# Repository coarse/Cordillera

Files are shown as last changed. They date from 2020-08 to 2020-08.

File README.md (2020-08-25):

# Cordillera



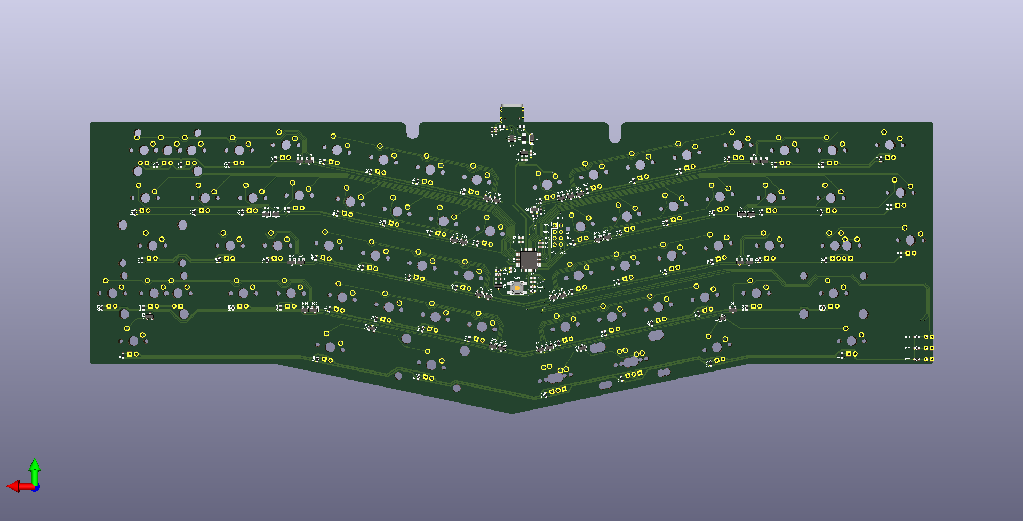
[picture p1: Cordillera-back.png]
Back PCB Render

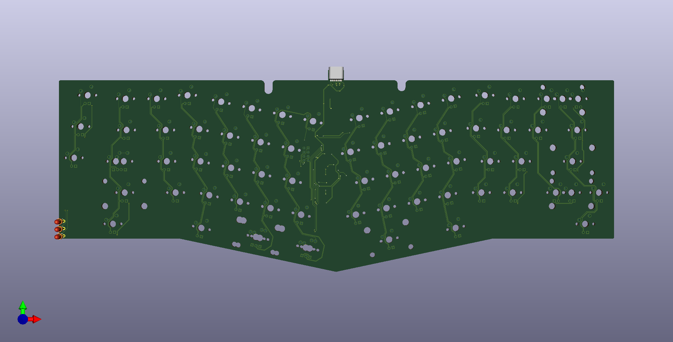
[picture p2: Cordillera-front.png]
Front PCB Render


## About

The Cordillera PCB is an open design PCB heavily based on the Alice PCB. The only breaking change is the USB connector which renders it unusable on most Alice cases.

- STM32F072 controller
- USB C connector mounted at the top
- ESD, over voltage, and over current protection circuits
- Dual common cathode diodes instead of single ones
- Backlight, single color
- Fancy "press to reset, hold for bootloader" reset circuit

## Dependencies

Symbols and footprints used are from my [KiCad library](https://github.com/coarse/KiCad-Keeb-Lib)

## Notes

- Original Alice uses USB Mini, so this PCB may be incompatible with some Alice cases

## Disclaimer

I provide this design as a reference for designing similar keyboard layout PCBs. Using them within your projects will require a will to do research of one's own and to learn the workings of them, potentially fixing issues if they exist.

I present the design as-is and as-available, without liability and without any guarantees regarding functionality, as expressed in the license.

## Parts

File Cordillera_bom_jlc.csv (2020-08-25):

Comment | Designator | Footprint | LCSC Part # | Manufacturer | Manufacturer Part Number
10n | C1 | keeb_parts:C_0603_1608Metric | C1589 | Samsung Electro-Mechanics | CL10B103KB8NNNC
100n | C2,C3,C5 | keeb_parts:C_0603_1608Metric | C1591 | Samsung Electro-Mechanics | CL10B104KB8NNNC
4.7n | C7 | keeb_parts:C_0603_1608Metric | C1621 | Samsung Electro-Mechanics | CL10B472KB8NNNC
4.7u | C6,C8,C11 | keeb_parts:C_0603_1608Metric | C1705 | Samsung Electro-Mechanics | CL10A475KP8NNNC
1u | C4,C9,C10,C12 | keeb_parts:C_0603_1608Metric | C1592 | Samsung Electro-Mechanics | CL10A105KO8NNNC
SMF6.0CA | D1 | keeb_parts:D_SOD-123 | C123791 | MDD(Microdiode Electronics) | SMF6.0CA
BAV70 | D2,D3,D4,D5,D6,D7,D8,D9,D10,D11,D12,D13,D14,D15,D16,D17,D18,D19,D20,D21,D22,D23,D24,D25,D26,D27,D28,D29,D30,D31,D32,D33,D34,D35,D36,D37 | keeb_parts:SOT-23 | C2501 | Nexperia | BAV70,215
1A | F1 | keeb_parts:Fuse_1206_3216Metric | C151162 | Littelfuse | 1206L050/15YR
2N7002 | Q1,Q2 | keeb_parts:SOT-23 | C65189 | Nexperia | 2N7002,215
1M | R1 | keeb_parts:R_0603_1608Metric | C26098 | UNI-ROYAL(Uniroyal Elec) | 0603WAJ0105T5E
5.1k | R2,R3 | keeb_parts:R_0603_1608Metric | C26000 | UNI-ROYAL(Uniroyal Elec) | 0603WAJ0512T5E
10k | R4,R6,R8 | keeb_parts:R_0603_1608Metric | C15401 | UNI-ROYAL(Uniroyal Elec) | 0603WAJ0103T5E
470 | R5,R9,R10,R11,R12,R13,R14,R15,R16,R17,R18,R19,R20,R21,R22,R23,R24,R25,R26,R27,R28,R29,R30,R31,R32,R33,R34,R35,R36,R37,R38,R39,R40,R41,R42,R43,R44,R45,R46,R47,R48,R49,R50,R51,R52,R53,R54,R55,R56,R57,R58,R59,R60,R61,R62,R63,R64,R65,R66,R67,R68,R69,R70,R71,R72,R73,R74,R75,R76,R77 | keeb_parts:R_0603_1608Metric | C1211 | UNI-ROYAL(Uniroyal Elec) | 0603WAJ0470T5E
100k | R7 | keeb_parts:R_0603_1608Metric | C15458 | UNI-ROYAL(Uniroyal Elec) | 0603WAJ0104T5E
SW_SPST | SW1 | keeb_parts:TactSwitch_SPST_5.1x5.1mm | C318884 | XKB Connectivity | TS-1187A-B-A-B
STM32F072CBTx | U1 | keeb_mcu:LQFP-48_7x7mm_P0.5mm | C81720 | STMicroelectronics | STM32F072CBT6
XC6206P332MR | U2 | keeb_parts:SOT-23 | C5446 | Torex Semicon | XC6206P332MR
SRV05-4 | U3 | keeb_parts:SOT-23-6 | C85364 | ProTek Devices | SRV05-4-P-T7
HRO-TYPE-C-31-M-12 | USB1 | keeb_connectors:HRO-TYPE-C-31-M-12 | C165948 | Korean Hroparts Elec | TYPE-C-31-M-12

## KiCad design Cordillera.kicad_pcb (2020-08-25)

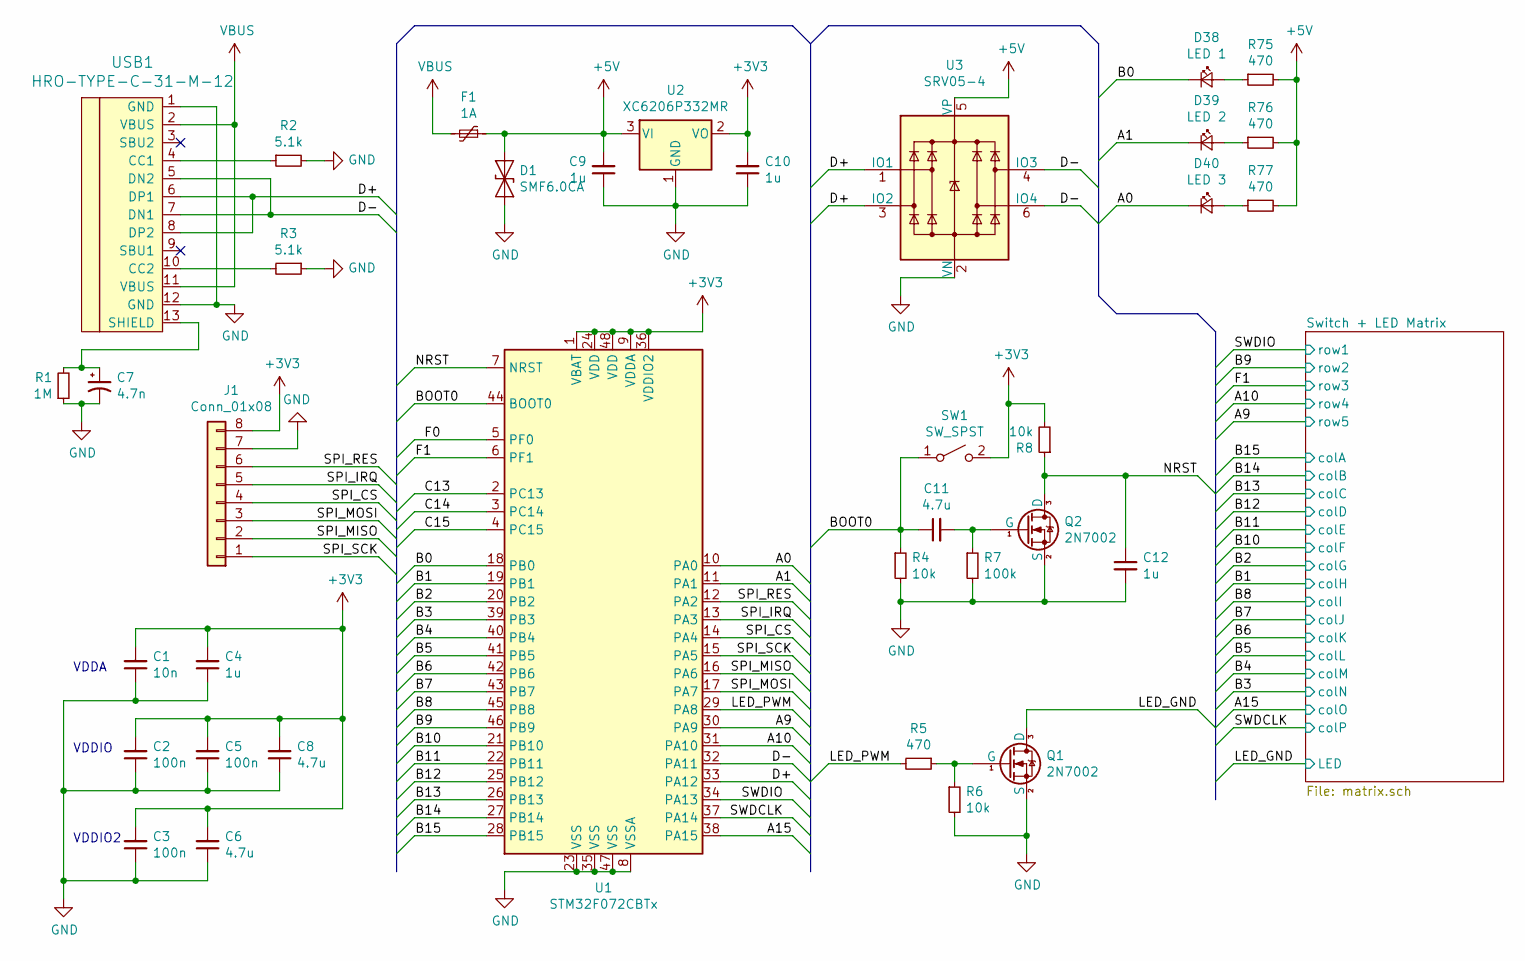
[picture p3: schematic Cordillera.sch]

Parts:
C1: 10n; C_0603_1608Metric
C2, C3, C5: 100n; C_0603_1608Metric
C4, C9, C10, C12: 1u; C_0603_1608Metric
C6, C8, C11: 4.7u; C_0603_1608Metric
C7: 4.7n; C_0603_1608Metric
D1: SMF6.0CA; D_SOD-123
D38: LED 1; LED_D3.0mm
D39: LED 2; LED_D3.0mm
D40: LED 3; LED_D3.0mm
F1: 1A; Fuse_1206_3216Metric
J1: Conn_01x08; PinHeader_2x04_P2.54mm_Vertical
Q1, Q2: 2N7002; SOT-23
R1: 1M; R_0603_1608Metric
R2, R3: 5.1k; R_0603_1608Metric
R4, R6, R8: 10k; R_0603_1608Metric
R5, R75, R76, R77: 470; R_0603_1608Metric
R7: 100k; R_0603_1608Metric
SW1: SW_SPST; TactSwitch_SPST_5.1x5.1mm
U1: STM32F072CBTx; LQFP-48_7x7mm_P0.5mm
U2: XC6206P332MR; SOT-23
U3: SRV05-4; SOT-23-6
USB1: HRO-TYPE-C-31-M-12

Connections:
+3V3: C1.2, C2.2, C3.2, C4.2, C5.2, C6.2, C8.2, C10.2, J1.8, R8.2, SW1.2 (B), U1.1 (VBAT), U1.9 (VDDA), U1.24 (VDD), U1.36 (VDDIO2), U1.48 (VDD), U2.2 (VO)
+5V: C9.2, D1.1 (A1), F1.1, R75.2, R76.2, R77.2, U2.3 (VI), U3.5 (VP); also elsewhere on the board
/A0: D40.1 (K), U1.10 (PA0)
/A1: D39.1 (K), U1.11 (PA1)
/A9: U1.30 (PA9); also elsewhere on the board
/A10: U1.31 (PA10); also elsewhere on the board
/A15: U1.38 (PA15); also elsewhere on the board
/B0: D38.1 (K), U1.18 (PB0)
/B1: U1.19 (PB1); also elsewhere on the board
/B2: U1.20 (PB2); also elsewhere on the board
/B3: U1.39 (PB3); also elsewhere on the board
/B4: U1.40 (PB4); also elsewhere on the board
/B5: U1.41 (PB5); also elsewhere on the board
/B6: U1.42 (PB6); also elsewhere on the board
/B7: U1.43 (PB7); also elsewhere on the board
/B8: U1.45 (PB8); also elsewhere on the board
/B9: U1.46 (PB9); also elsewhere on the board
/B10: U1.21 (PB10); also elsewhere on the board
/B11: U1.22 (PB11); also elsewhere on the board
/B12: U1.25 (PB12); also elsewhere on the board
/B13: U1.26 (PB13); also elsewhere on the board
/B14: U1.27 (PB14); also elsewhere on the board
/B15: U1.28 (PB15); also elsewhere on the board
/BOOT0: C11.1, R4.1, SW1.1 (A), U1.44 (BOOT0)
/C13: U1.2 (PC13)
/C14: U1.3 (PC14)
/C15: U1.4 (PC15)
/D+: U1.33 (PA12), U3.1 (IO1), U3.3 (IO2), USB1.6 (DP1), USB1.8 (DP2)
/D-: U1.32 (PA11), U3.4 (IO3), U3.6 (IO4), USB1.5 (DN2), USB1.7 (DN1)
/F0: U1.5 (PF0)
/F1: U1.6 (PF1); also elsewhere on the board
/LED_GND: Q1.3 (D); also elsewhere on the board
/LED_PWM: R5.2, U1.29 (PA8)
/NRST: C12.1, Q2.3 (D), R8.1, U1.7 (NRST)
/SPI_CS: J1.4, U1.14 (PA4)
/SPI_IRQ: J1.5, U1.13 (PA3)
/SPI_MISO: J1.2, U1.16 (PA6)
/SPI_MOSI: J1.3, U1.17 (PA7)
/SPI_RES: J1.6, U1.12 (PA2)
/SPI_SCK: J1.1, U1.15 (PA5)
/SWDCLK: U1.37 (PA14); also elsewhere on the board
/SWDIO: U1.34 (PA13); also elsewhere on the board
GND: C1.1, C2.1, C3.1, C4.1, C5.1, C6.1, C7.2, C8.1, C9.1, C10.1, C12.2, D1.2 (A2), J1.7, Q1.2 (S), Q2.2 (S), R1.1, R2.2, R3.1, R4.2, R6.2, R7.2, U1.8 (VSSA), U1.23 (VSS), U1.35 (VSS), U1.47 (VSS), U2.1 (GND), U3.2 (VN), USB1.1 (GND), USB1.12 (GND)
unnamed: C7.1, R1.2, USB1.13 (SHIELD)
unnamed: C11.2, Q2.1 (G), R7.1
unnamed: D38.2 (A), R75.1
unnamed: D39.2 (A), R76.1
unnamed: D40.2 (A), R77.1
unnamed: Q1.1 (G), R5.1, R6.1
unnamed: R2.1, USB1.4 (CC1)
unnamed: R3.2, USB1.10 (CC2)
VBUS: F1.2, USB1.2 (VBUS), USB1.11 (VBUS)

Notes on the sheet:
VDDIO
VDDIO2
VDDA

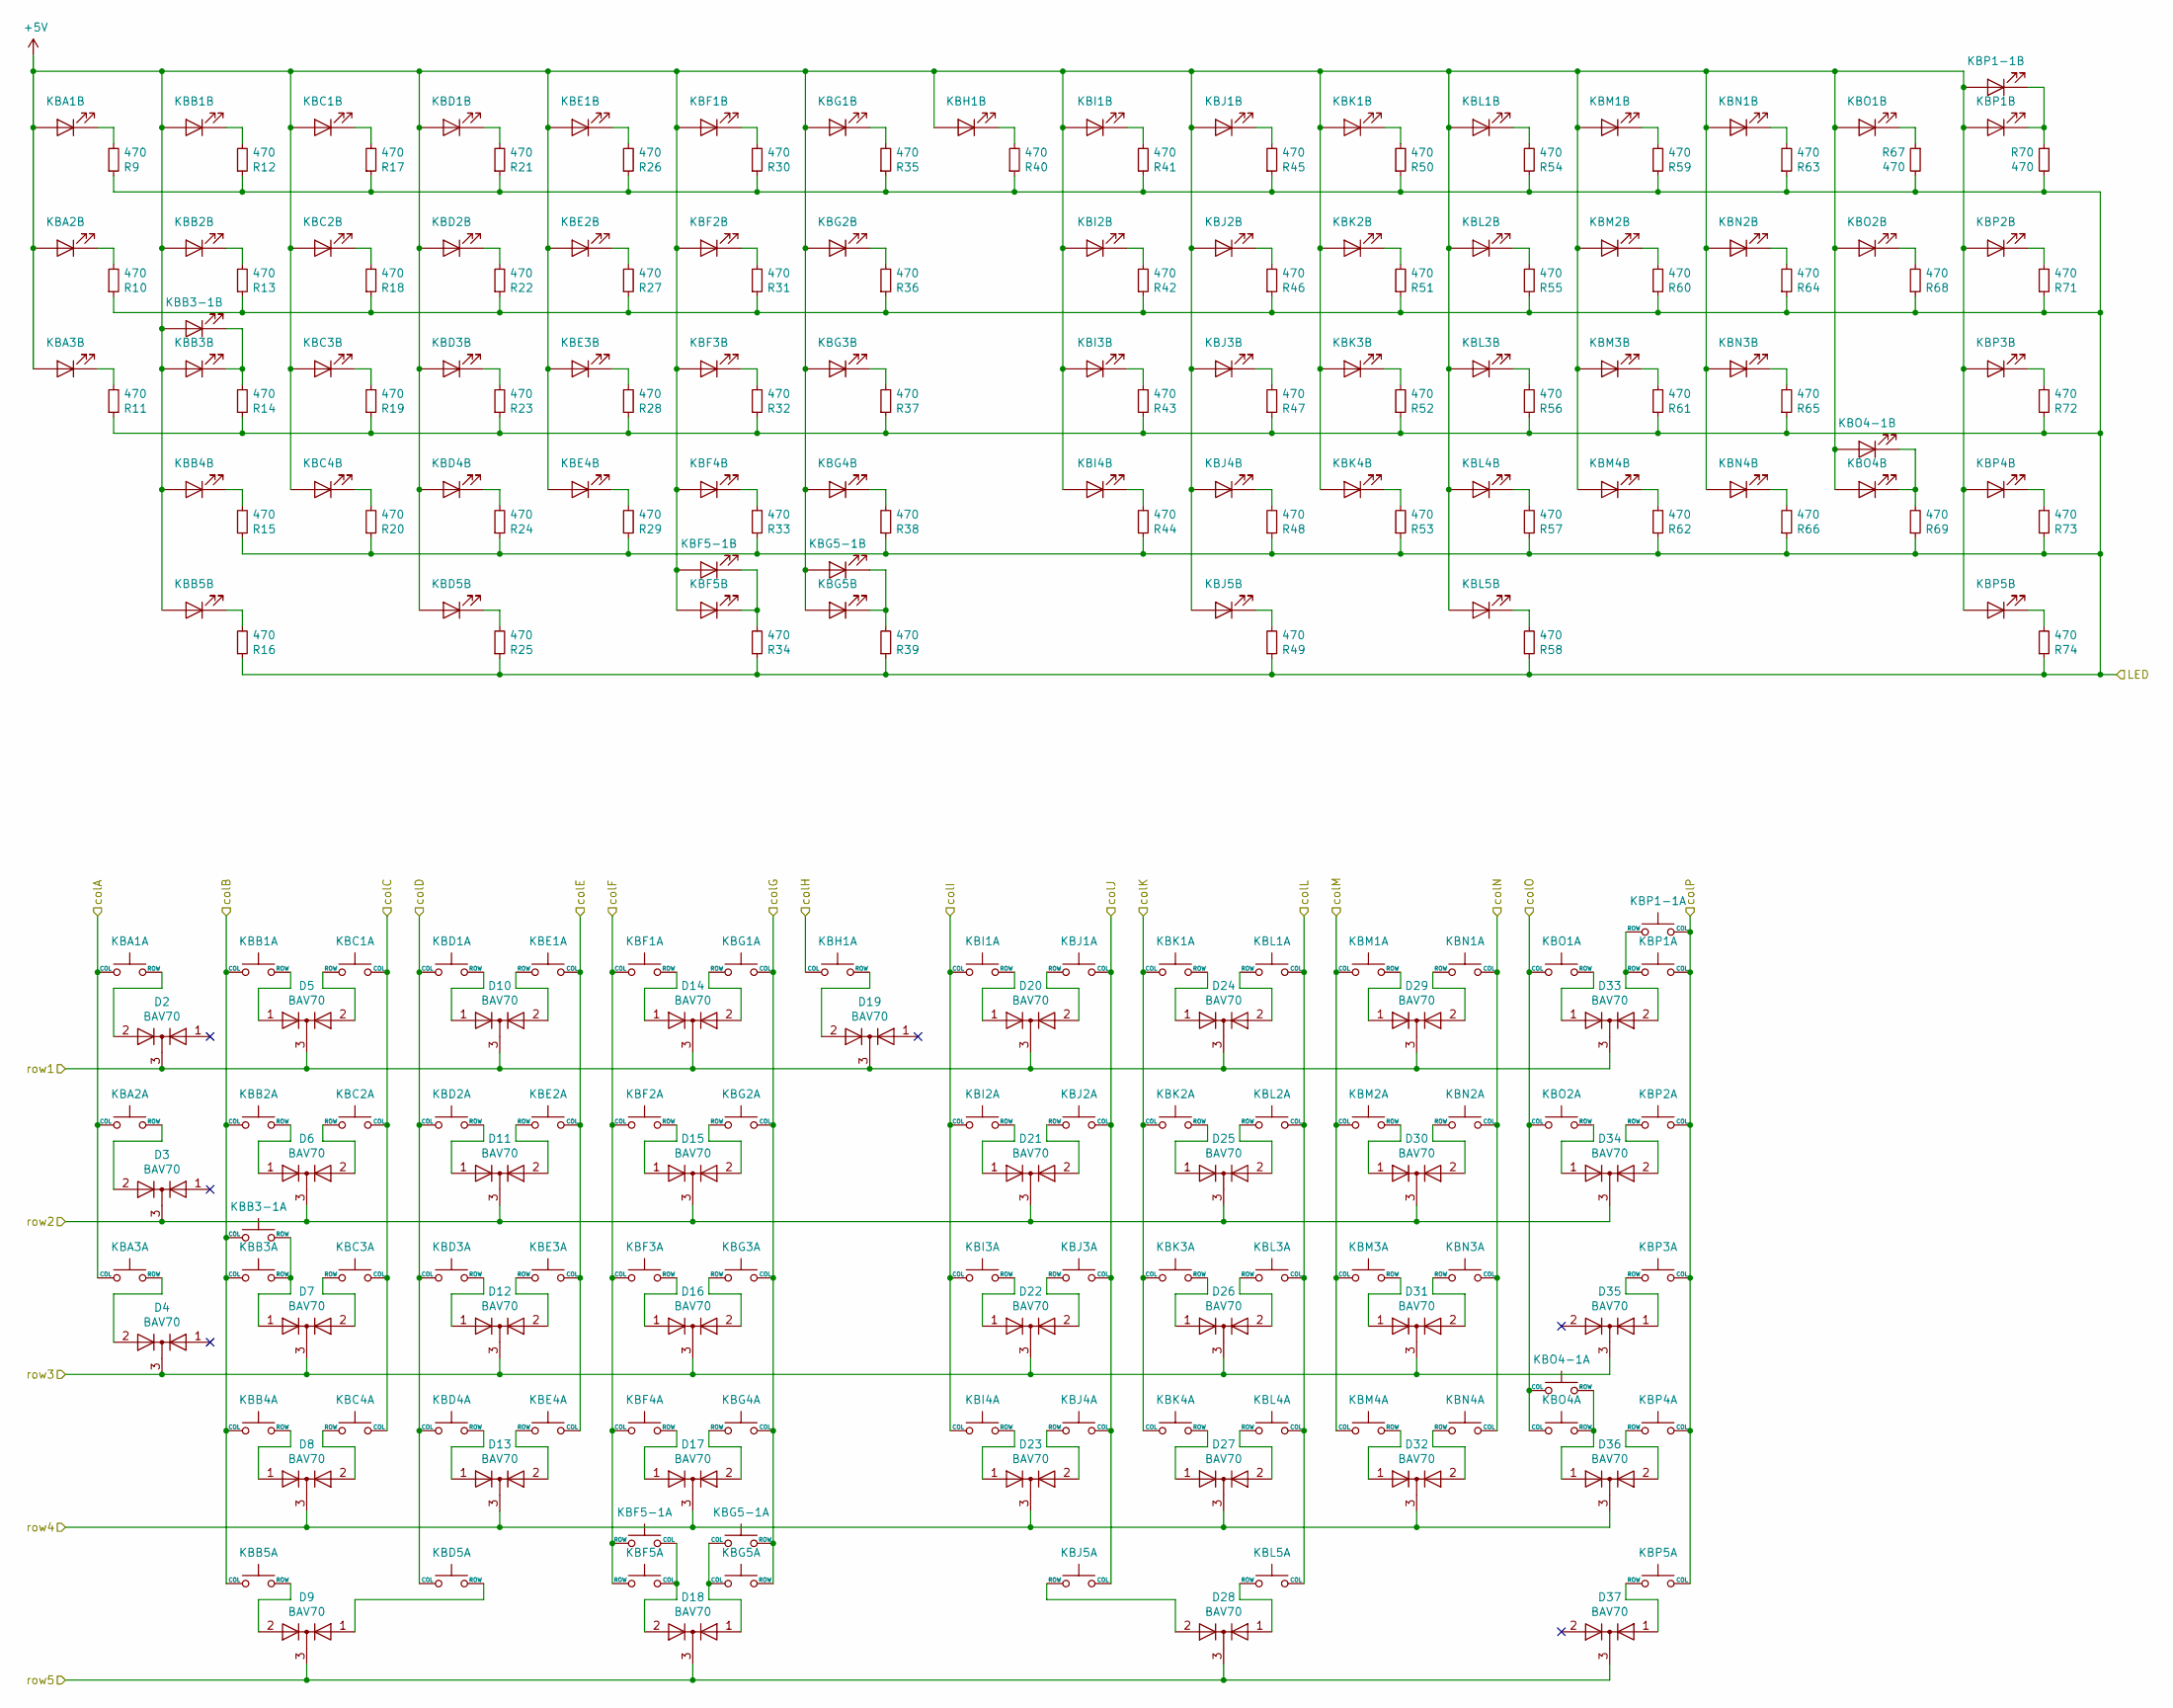
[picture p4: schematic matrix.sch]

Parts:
D2, D3, D4, D5, D6, D7, D8, D9, D10, D11, D12, D13, D14, D15, D16, D17, D18, D19, D20, D21, D22, D23, D24, D25, D26, D27, D28, D29, D30, D31, D32, D33, D34, D35, D36, D37: BAV70; SOT-23
KBA1, KBA2, KBA3: Keyboard_Switch; MXOnly-1U
KBB1: Keyboard_Switch; MXOnly-1U
KBB2, KBB5: Keyboard_Switch; MXOnly-1.5U
KBB3: Keyboard_Switch; MXOnly-1.75U
KBB3-1: Keyboard_Switch; MXOnly-1.25U-FLIPPED
KBB4: Keyboard_Switch; MXOnly-2.25U
KBC1, KBC2, KBC3, KBC4: Keyboard_Switch; MXOnly-1U
KBD1, KBD2, KBD3, KBD4: Keyboard_Switch; MXOnly-1U
KBD5: Keyboard_Switch; MXOnly-1.5U
KBE1, KBE2, KBE3, KBE4: Keyboard_Switch; MXOnly-1U
KBF1, KBF2, KBF3, KBF4: Keyboard_Switch; MXOnly-1U
KBF5: Keyboard_Switch; MXOnly-2U-FLIPPED-ReversedStabilizers
KBF5-1: Keyboard_Switch; MXOnly-2.25U-ReversedStabilizers
KBG1, KBG2, KBG3, KBG4, KBG5-1: Keyboard_Switch; MXOnly-1U
KBG5: Keyboard_Switch; MXOnly-1.25U-FLIPPED
KBH1: Keyboard_Switch; MXOnly-1U
KBI1, KBI2, KBI3, KBI4: Keyboard_Switch; MXOnly-1U
KBJ1, KBJ2, KBJ3, KBJ4: Keyboard_Switch; MXOnly-1U
KBJ5: Keyboard_Switch; MXOnly-2.75U-ReversedStabilizers
KBK1, KBK2, KBK3, KBK4: Keyboard_Switch; MXOnly-1U
KBL1, KBL2, KBL3, KBL4: Keyboard_Switch; MXOnly-1U
KBL5: Keyboard_Switch; MXOnly-1.5U
KBM1, KBM2, KBM3, KBM4: Keyboard_Switch; MXOnly-1U
KBN1, KBN2, KBN3, KBN4: Keyboard_Switch; MXOnly-1U
KBO1, KBO2: Keyboard_Switch; MXOnly-1U
KBO4: Keyboard_Switch; MXOnly-2.75U
KBO4-1: Keyboard_Switch; MXOnly-1.75U-FLIPPED
KBP1: Keyboard_Switch; MXOnly-2U
KBP1-1: Keyboard_Switch; MXOnly-1U-FLIPPED
KBP2, KBP5: Keyboard_Switch; MXOnly-1.5U
KBP3: Keyboard_Switch; MXOnly-2.25U-ReversedStabilizers
KBP4: Keyboard_Switch; MXOnly-1U
R9, R10, R11, R12, R13, R14, R15, R16, R17, R18, R19, R20, R21, R22, R23, R24, R25, R26, R27, R28, R29, R30, R31, R32, R33, R34, R35, R36, R37, R38, R39, R40, R41, R42, R43, R44, R45, R46, R47, R48, R49, R50, R51, R52, R53, R54, R55, R56, R57, R58, R59, R60, R61, R62, R63, R64, R65, R66, R67, R68, R69, R70, R71, R72, R73, R74: 470; R_0603_1608Metric

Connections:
+5V: KBA1.3 (LED), KBA2.3 (LED), KBA3.3 (LED), KBB1.3 (LED), KBB2.3 (LED), KBB3.3 (LED), KBB3-1.3 (LED), KBB4.3 (LED), KBB5.3 (LED), KBC1.3 (LED), KBC2.3 (LED), KBC3.3 (LED), KBC4.3 (LED), KBD1.3 (LED), KBD2.3 (LED), KBD3.3 (LED), KBD4.3 (LED), KBD5.3 (LED), KBE1.3 (LED), KBE2.3 (LED), KBE3.3 (LED), KBE4.3 (LED), KBF1.3 (LED), KBF2.3 (LED), KBF3.3 (LED), KBF4.3 (LED), KBF5.3 (LED), KBF5-1.3 (LED), KBG1.3 (LED), KBG2.3 (LED), KBG3.3 (LED), KBG4.3 (LED), KBG5.3 (LED), KBG5-1.3 (LED), KBH1.3 (LED), KBI1.3 (LED), KBI2.3 (LED), KBI3.3 (LED), KBI4.3 (LED), KBJ1.3 (LED), KBJ2.3 (LED), KBJ3.3 (LED), KBJ4.3 (LED), KBJ5.3 (LED), KBK1.3 (LED), KBK2.3 (LED), KBK3.3 (LED), KBK4.3 (LED), KBL1.3 (LED), KBL2.3 (LED), KBL3.3 (LED), KBL4.3 (LED), KBL5.3 (LED), KBM1.3 (LED), KBM2.3 (LED), KBM3.3 (LED), KBM4.3 (LED), KBN1.3 (LED), KBN2.3 (LED), KBN3.3 (LED), KBN4.3 (LED), KBO1.3 (LED), KBO2.3 (LED), KBO4.3 (LED), KBO4-1.3 (LED), KBP1.3 (LED), KBP1-1.3 (LED), KBP2.3 (LED), KBP3.3 (LED), KBP4.3 (LED), KBP5.3 (LED); also elsewhere on the board
/A9: D9.3 (K), D18.3 (K), D28.3 (K), D37.3 (K); also elsewhere on the board
/A10: D8.3 (K), D13.3 (K), D17.3 (K), D23.3 (K), D27.3 (K), D32.3 (K), D36.3 (K); also elsewhere on the board
/A15: KBO1.1 (COL), KBO2.1 (COL), KBO4.1 (COL), KBO4-1.1 (COL); also elsewhere on the board
/B1: KBH1.1 (COL); also elsewhere on the board
/B2: KBG1.1 (COL), KBG2.1 (COL), KBG3.1 (COL), KBG4.1 (COL), KBG5.2 (ROW), KBG5-1.2 (ROW); also elsewhere on the board
/B3: KBN1.1 (COL), KBN2.1 (COL), KBN3.1 (COL), KBN4.1 (COL); also elsewhere on the board
/B4: KBM1.1 (COL), KBM2.1 (COL), KBM3.1 (COL), KBM4.1 (COL); also elsewhere on the board
/B5: KBL1.1 (COL), KBL2.1 (COL), KBL3.1 (COL), KBL4.1 (COL), KBL5.1 (COL); also elsewhere on the board
/B6: KBK1.1 (COL), KBK2.1 (COL), KBK3.1 (COL), KBK4.1 (COL); also elsewhere on the board
/B7: KBJ1.1 (COL), KBJ2.1 (COL), KBJ3.1 (COL), KBJ4.1 (COL), KBJ5.1 (COL); also elsewhere on the board
/B8: KBI1.1 (COL), KBI2.1 (COL), KBI3.1 (COL), KBI4.1 (COL); also elsewhere on the board
/B9: D3.3 (K), D6.3 (K), D11.3 (K), D15.3 (K), D21.3 (K), D25.3 (K), D30.3 (K), D34.3 (K); also elsewhere on the board
/B10: KBF1.1 (COL), KBF2.1 (COL), KBF3.1 (COL), KBF4.1 (COL), KBF5.2 (ROW), KBF5-1.2 (ROW); also elsewhere on the board
/B11: KBE1.1 (COL), KBE2.1 (COL), KBE3.1 (COL), KBE4.1 (COL); also elsewhere on the board
/B12: KBD1.1 (COL), KBD2.1 (COL), KBD3.1 (COL), KBD4.1 (COL), KBD5.1 (COL); also elsewhere on the board
/B13: KBC1.1 (COL), KBC2.1 (COL), KBC3.1 (COL), KBC4.1 (COL); also elsewhere on the board
/B14: KBB1.1 (COL), KBB2.1 (COL), KBB3.1 (COL), KBB3-1.1 (COL), KBB4.1 (COL), KBB5.1 (COL); also elsewhere on the board
/B15: KBA1.1 (COL), KBA2.1 (COL), KBA3.1 (COL); also elsewhere on the board
/F1: D4.3 (K), D7.3 (K), D12.3 (K), D16.3 (K), D22.3 (K), D26.3 (K), D31.3 (K), D35.3 (K); also elsewhere on the board
/LED_GND: R9.1, R10.1, R11.1, R12.1, R13.1, R14.1, R15.1, R16.1, R17.1, R18.1, R19.1, R20.1, R21.1, R22.1, R23.1, R24.1, R25.1, R26.1, R27.1, R28.1, R29.1, R30.1, R31.1, R32.1, R33.1, R34.1, R35.1, R36.1, R37.1, R38.1, R39.1, R40.1, R41.1, R42.1, R43.1, R44.1, R45.1, R46.1, R47.1, R48.1, R49.1, R50.1, R51.1, R52.1, R53.1, R54.1, R55.1, R56.1, R57.1, R58.1, R59.1, R60.1, R61.1, R62.1, R63.1, R64.1, R65.1, R66.1, R67.2, R68.1, R69.1, R70.2, R71.1, R72.1, R73.1, R74.1; also elsewhere on the board
/SWDCLK: KBP1.1 (COL), KBP1-1.1 (COL), KBP2.1 (COL), KBP3.1 (COL), KBP4.1 (COL), KBP5.1 (COL); also elsewhere on the board
/SWDIO: D2.3 (K), D5.3 (K), D10.3 (K), D14.3 (K), D19.3 (K), D20.3 (K), D24.3 (K), D29.3 (K), D33.3 (K); also elsewhere on the board
unnamed: D2.2 (A), KBA1.2 (ROW)
unnamed: D3.2 (A), KBA2.2 (ROW)
unnamed: D4.2 (A), KBA3.2 (ROW)
unnamed: D5.1 (A), KBB1.2 (ROW)
unnamed: D5.2 (A), KBC1.2 (ROW)
unnamed: D6.1 (A), KBB2.2 (ROW)
unnamed: D6.2 (A), KBC2.2 (ROW)
unnamed: D7.1 (A), KBB3.2 (ROW), KBB3-1.2 (ROW)
unnamed: D7.2 (A), KBC3.2 (ROW)
unnamed: D8.1 (A), KBB4.2 (ROW)
unnamed: D8.2 (A), KBC4.2 (ROW)
unnamed: D9.1 (A), KBD5.2 (ROW)
unnamed: D9.2 (A), KBB5.2 (ROW)
unnamed: D10.1 (A), KBD1.2 (ROW)
unnamed: D10.2 (A), KBE1.2 (ROW)
unnamed: D11.1 (A), KBD2.2 (ROW)
unnamed: D11.2 (A), KBE2.2 (ROW)
unnamed: D12.1 (A), KBD3.2 (ROW)
unnamed: D12.2 (A), KBE3.2 (ROW)
unnamed: D13.1 (A), KBD4.2 (ROW)
unnamed: D13.2 (A), KBE4.2 (ROW)
unnamed: D14.1 (A), KBF1.2 (ROW)
unnamed: D14.2 (A), KBG1.2 (ROW)
unnamed: D15.1 (A), KBF2.2 (ROW)
unnamed: D15.2 (A), KBG2.2 (ROW)
unnamed: D16.1 (A), KBF3.2 (ROW)
unnamed: D16.2 (A), KBG3.2 (ROW)
unnamed: D17.1 (A), KBF4.2 (ROW)
unnamed: D17.2 (A), KBG4.2 (ROW)
unnamed: D18.1 (A), KBG5.1 (COL), KBG5-1.1 (COL)
unnamed: D18.2 (A), KBF5.1 (COL), KBF5-1.1 (COL)
unnamed: D19.2 (A), KBH1.2 (ROW)
unnamed: D20.1 (A), KBI1.2 (ROW)
unnamed: D20.2 (A), KBJ1.2 (ROW)
unnamed: D21.1 (A), KBI2.2 (ROW)
unnamed: D21.2 (A), KBJ2.2 (ROW)
unnamed: D22.1 (A), KBI3.2 (ROW)
unnamed: D22.2 (A), KBJ3.2 (ROW)
unnamed: D23.1 (A), KBI4.2 (ROW)
unnamed: D23.2 (A), KBJ4.2 (ROW)
unnamed: D24.1 (A), KBK1.2 (ROW)
unnamed: D24.2 (A), KBL1.2 (ROW)
unnamed: D25.1 (A), KBK2.2 (ROW)
unnamed: D25.2 (A), KBL2.2 (ROW)
unnamed: D26.1 (A), KBK3.2 (ROW)
unnamed: D26.2 (A), KBL3.2 (ROW)
unnamed: D27.1 (A), KBK4.2 (ROW)
unnamed: D27.2 (A), KBL4.2 (ROW)
unnamed: D28.1 (A), KBL5.2 (ROW)
unnamed: D28.2 (A), KBJ5.2 (ROW)
unnamed: D29.1 (A), KBM1.2 (ROW)
unnamed: D29.2 (A), KBN1.2 (ROW)
unnamed: D30.1 (A), KBM2.2 (ROW)
unnamed: D30.2 (A), KBN2.2 (ROW)
unnamed: D31.1 (A), KBM3.2 (ROW)
unnamed: D31.2 (A), KBN3.2 (ROW)
unnamed: D32.1 (A), KBM4.2 (ROW)
unnamed: D32.2 (A), KBN4.2 (ROW)
unnamed: D33.1 (A), KBO1.2 (ROW)
unnamed: D33.2 (A), KBP1.2 (ROW), KBP1-1.2 (ROW)
unnamed: D34.1 (A), KBO2.2 (ROW)
unnamed: D34.2 (A), KBP2.2 (ROW)
unnamed: D35.1 (A), KBP3.2 (ROW)
unnamed: D36.1 (A), KBO4.2 (ROW), KBO4-1.2 (ROW)
unnamed: D36.2 (A), KBP4.2 (ROW)
unnamed: D37.1 (A), KBP5.2 (ROW)
unnamed: KBA1.4 (LEDGND), R9.2
unnamed: KBA2.4 (LEDGND), R10.2
unnamed: KBA3.4 (LEDGND), R11.2
unnamed: KBB1.4 (LEDGND), R12.2
unnamed: KBB2.4 (LEDGND), R13.2
unnamed: KBB3.4 (LEDGND), KBB3-1.4 (LEDGND), R14.2
unnamed: KBB4.4 (LEDGND), R15.2
unnamed: KBB5.4 (LEDGND), R16.2
unnamed: KBC1.4 (LEDGND), R17.2
unnamed: KBC2.4 (LEDGND), R18.2
unnamed: KBC3.4 (LEDGND), R19.2
unnamed: KBC4.4 (LEDGND), R20.2
unnamed: KBD1.4 (LEDGND), R21.2
unnamed: KBD2.4 (LEDGND), R22.2
unnamed: KBD3.4 (LEDGND), R23.2
unnamed: KBD4.4 (LEDGND), R24.2
unnamed: KBD5.4 (LEDGND), R25.2
unnamed: KBE1.4 (LEDGND), R26.2
unnamed: KBE2.4 (LEDGND), R27.2
unnamed: KBE3.4 (LEDGND), R28.2
unnamed: KBE4.4 (LEDGND), R29.2
unnamed: KBF1.4 (LEDGND), R30.2
unnamed: KBF2.4 (LEDGND), R31.2
unnamed: KBF3.4 (LEDGND), R32.2
unnamed: KBF4.4 (LEDGND), R33.2
unnamed: KBF5.4 (LEDGND), KBF5-1.4 (LEDGND), R34.2
unnamed: KBG1.4 (LEDGND), R35.2
unnamed: KBG2.4 (LEDGND), R36.2
unnamed: KBG3.4 (LEDGND), R37.2
unnamed: KBG4.4 (LEDGND), R38.2
unnamed: KBG5.4 (LEDGND), KBG5-1.4 (LEDGND), R39.2
unnamed: KBH1.4 (LEDGND), R40.2
unnamed: KBI1.4 (LEDGND), R41.2
unnamed: KBI2.4 (LEDGND), R42.2
unnamed: KBI3.4 (LEDGND), R43.2
unnamed: KBI4.4 (LEDGND), R44.2
unnamed: KBJ1.4 (LEDGND), R45.2
unnamed: KBJ2.4 (LEDGND), R46.2
unnamed: KBJ3.4 (LEDGND), R47.2
unnamed: KBJ4.4 (LEDGND), R48.2
unnamed: KBJ5.4 (LEDGND), R49.2
unnamed: KBK1.4 (LEDGND), R50.2
unnamed: KBK2.4 (LEDGND), R51.2
unnamed: KBK3.4 (LEDGND), R52.2
unnamed: KBK4.4 (LEDGND), R53.2
unnamed: KBL1.4 (LEDGND), R54.2
unnamed: KBL2.4 (LEDGND), R55.2
unnamed: KBL3.4 (LEDGND), R56.2
unnamed: KBL4.4 (LEDGND), R57.2
unnamed: KBL5.4 (LEDGND), R58.2
unnamed: KBM1.4 (LEDGND), R59.2
unnamed: KBM2.4 (LEDGND), R60.2
unnamed: KBM3.4 (LEDGND), R61.2
unnamed: KBM4.4 (LEDGND), R62.2
unnamed: KBN1.4 (LEDGND), R63.2
unnamed: KBN2.4 (LEDGND), R64.2
unnamed: KBN3.4 (LEDGND), R65.2
unnamed: KBN4.4 (LEDGND), R66.2
unnamed: KBO1.4 (LEDGND), R67.1
unnamed: KBO2.4 (LEDGND), R68.2
unnamed: KBO4.4 (LEDGND), KBO4-1.4 (LEDGND), R69.2
unnamed: KBP1.4 (LEDGND), KBP1-1.4 (LEDGND), R70.1
unnamed: KBP2.4 (LEDGND), R71.2
unnamed: KBP3.4 (LEDGND), R72.2
unnamed: KBP4.4 (LEDGND), R73.2
unnamed: KBP5.4 (LEDGND), R74.2

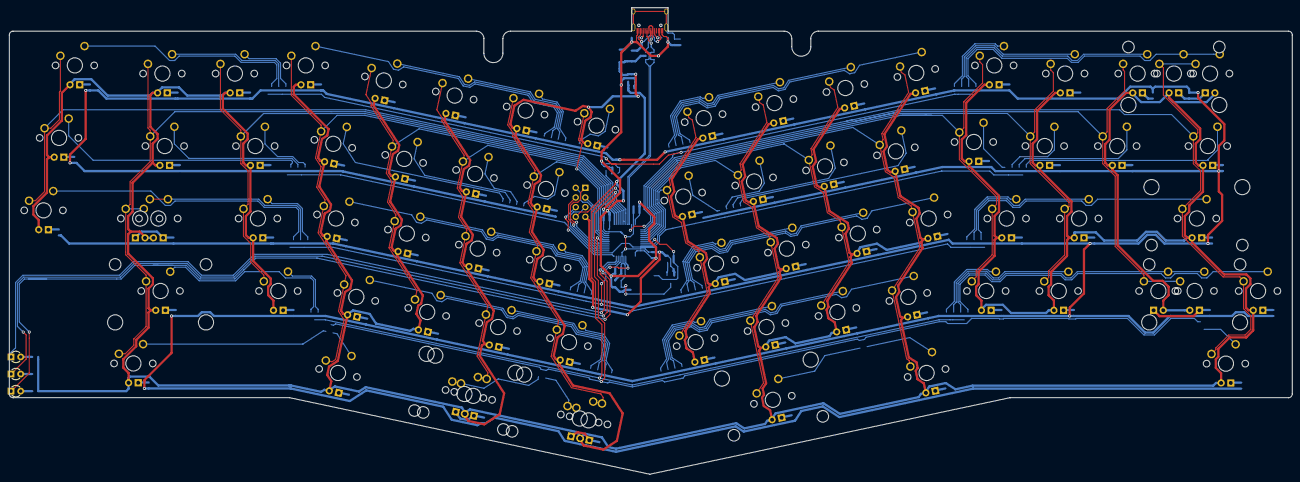
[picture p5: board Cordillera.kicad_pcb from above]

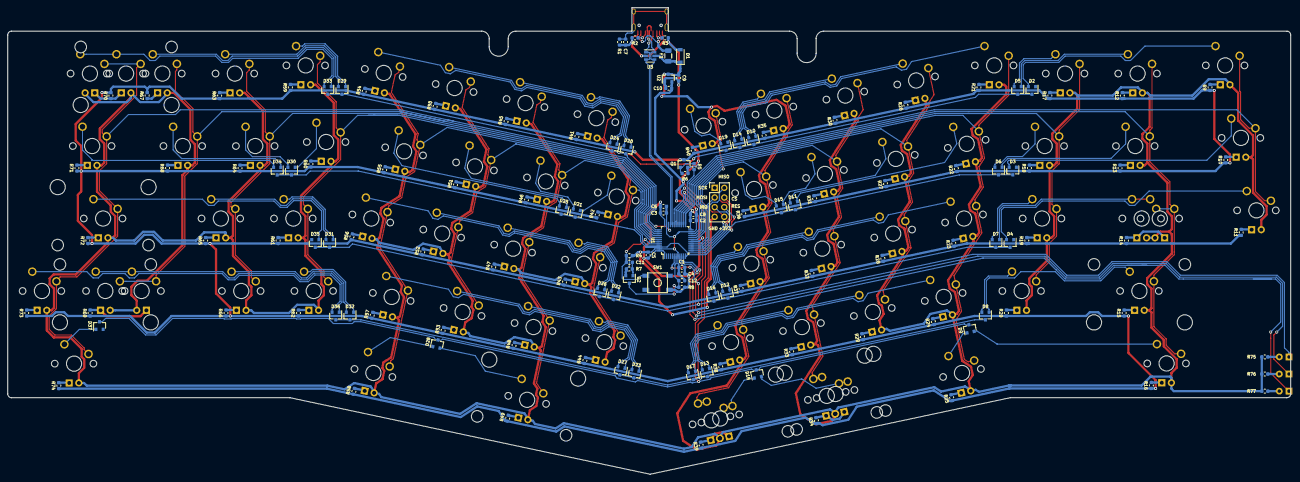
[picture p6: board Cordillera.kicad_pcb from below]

Board: 2 copper layers, 337.2 x 122.6 mm, 209 parts (134 on the bottom side), 180 nets.

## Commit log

2020-08-09 Remove plate drawing
    [alice_PCB_layout.DWG]
2020-08-09 Add indicator LEDs
    [Cordillera.kicad_pcb, Cordillera.sch, matrix.sch]
2020-08-09 Lay out switch and LED matrix components
    [Cordillera.kicad_pcb, matrix.sch]
2020-08-09 Finish routing LED matrix
    [Cordillera.kicad_pcb, matrix.sch]
2020-08-10 Do some routing
    [Cordillera.kicad_pcb, matrix.sch]
2020-08-11 Finish routing switches
    [Cordillera.kicad_pcb, Cordillera.sch, matrix.sch]
2020-08-11 Finish column routing
    [Cordillera.kicad_pcb, Cordillera.sch]
2020-08-25 Update files
    [Cordillera-B_Cu.gbr, Cordillera-B_Mask.gbr, Cordillera-B_Paste.gbr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]
2020-08-25 Add renders
    [Cordillera.kicad_pcb]
2020-08-25 fix indicator leds
    [Cordillera-B_Cu.gbr, Cordillera-B_Mask.gbr, Cordillera-B_Paste.gbr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]

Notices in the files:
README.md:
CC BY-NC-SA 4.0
